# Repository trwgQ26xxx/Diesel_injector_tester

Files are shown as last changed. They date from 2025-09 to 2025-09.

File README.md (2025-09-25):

# Diesel Injector Tester

**A small tester generating short 200 µs pulses needed for testing the opening of electromagnetic diesel injectors with a selectable repetition period.**

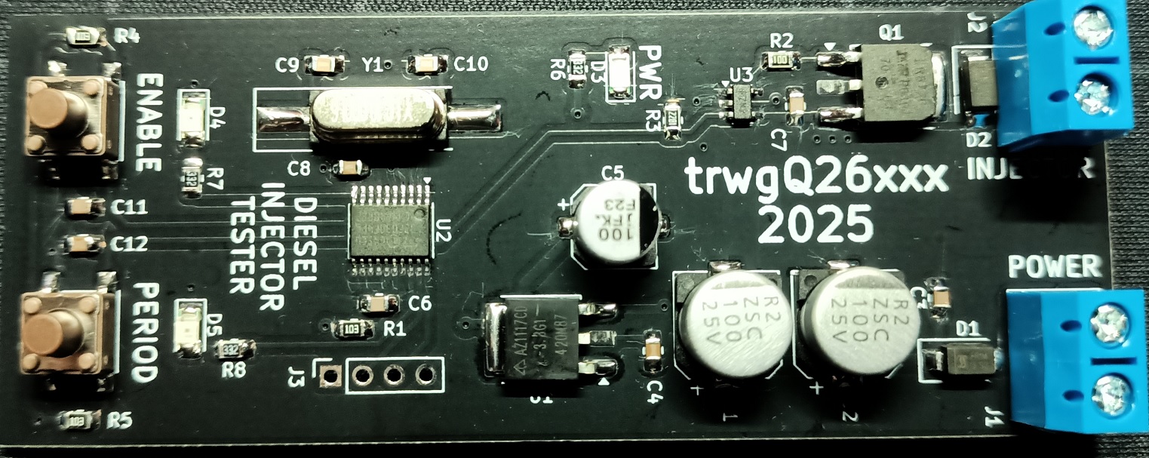
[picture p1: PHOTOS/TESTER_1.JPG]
TESTER_1


Generates high-current, short pulses (200us) with a selectable repetition rate: 0.2Hz, 0.5Hz, 1Hz, 2Hz, 5Hz, or 10Hz.

The tester is operated using two buttons:

* *ENABLE* - Toggles the high-current output on or off.
* *PERIOD* - Cycles through available repetition rates.

Status is indicated by two LEDs:

* *PERIOD* LED blinks at the selected repetition rate.
* *ENABLE* LED is lit when the high-current output is active.

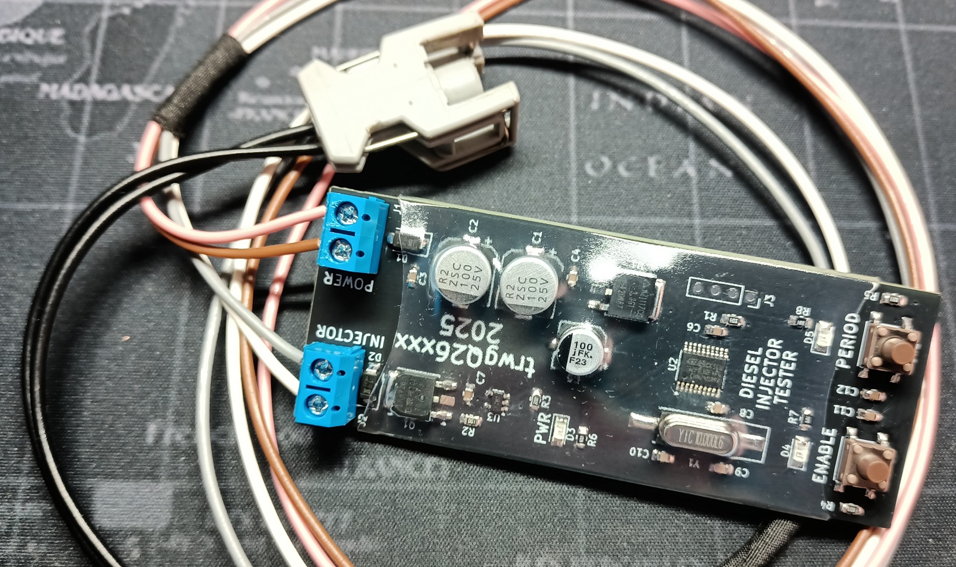
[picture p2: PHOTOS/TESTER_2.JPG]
TESTER_2


# Disclaimer

I do not consent to the use of all or part of the project for commercial purposes!

Nie wyrażam zgody na wykorzystanie całości bądź części projektu w celach zarobkowych!

# License

Shield: [][cc-by-nc-sa]

This work is licensed under a
[Creative Commons Attribution-NonCommercial-ShareAlike 4.0 International License][cc-by-nc-sa].

[][cc-by-nc-sa]

[cc-by-nc-sa]: http://creativecommons.org/licenses/by-nc-sa/4.0/
[cc-by-nc-sa-image]: https://licensebuttons.net/l/by-nc-sa/4.0/88x31.png
[cc-by-nc-sa-shield]: https://img.shields.io/badge/License-CC%20BY--NC--SA%204.0-lightgrey.svg

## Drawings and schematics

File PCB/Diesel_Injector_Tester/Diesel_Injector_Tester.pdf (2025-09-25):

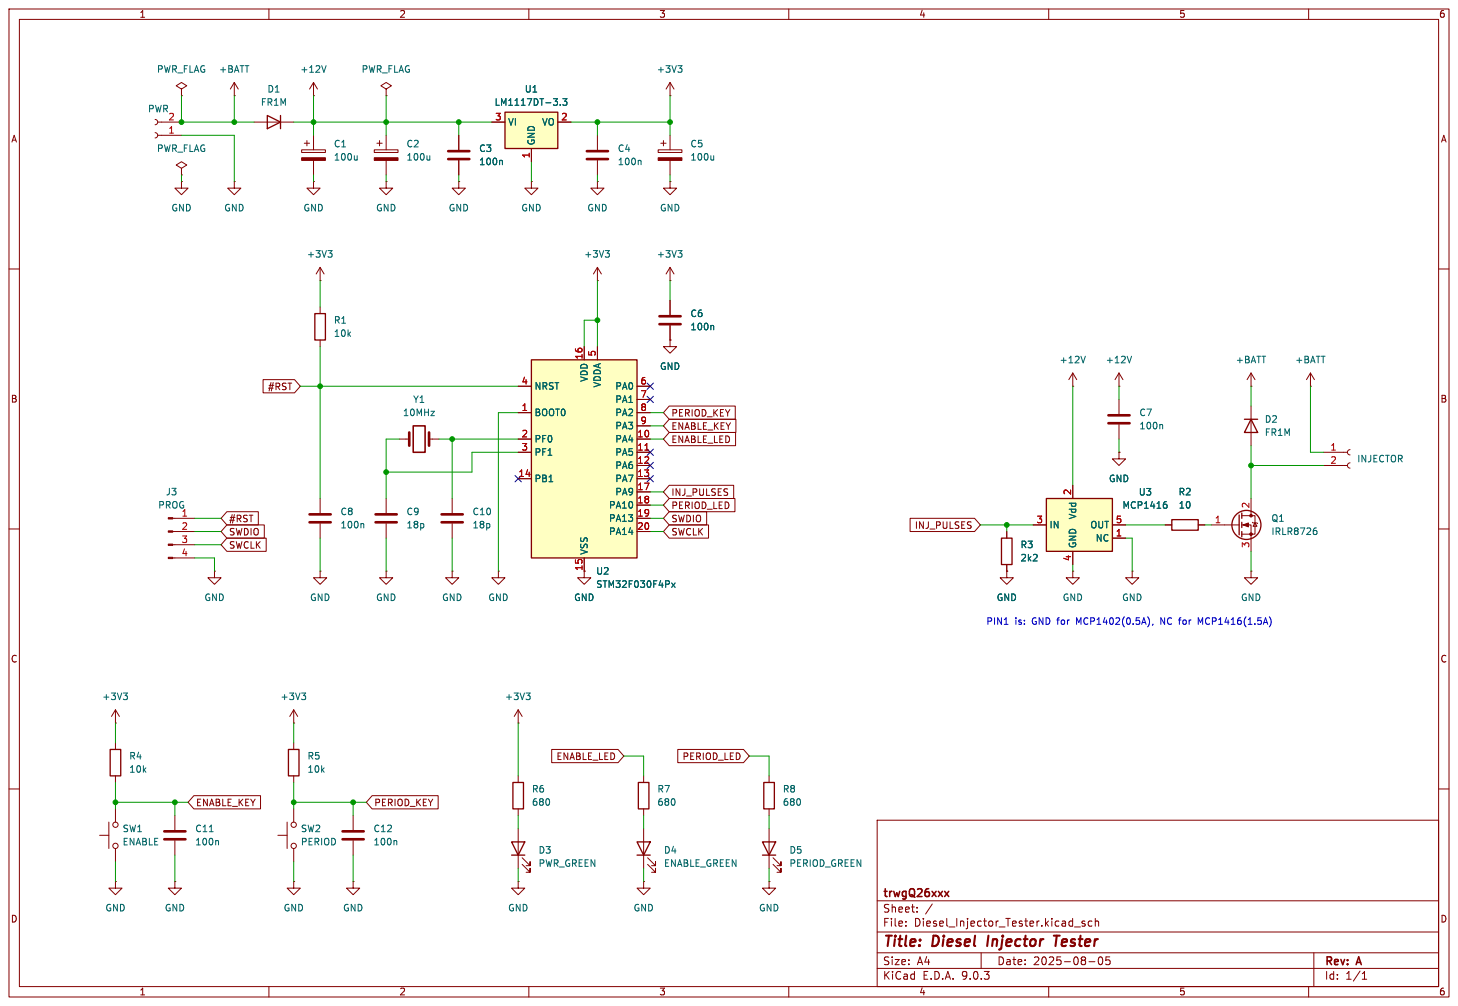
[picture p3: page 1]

Id: 1/1 Title: Diesel Injector Tester File: Diesel_Injector_Tester.kicad_sch Sheet: / trwgQ26xxx

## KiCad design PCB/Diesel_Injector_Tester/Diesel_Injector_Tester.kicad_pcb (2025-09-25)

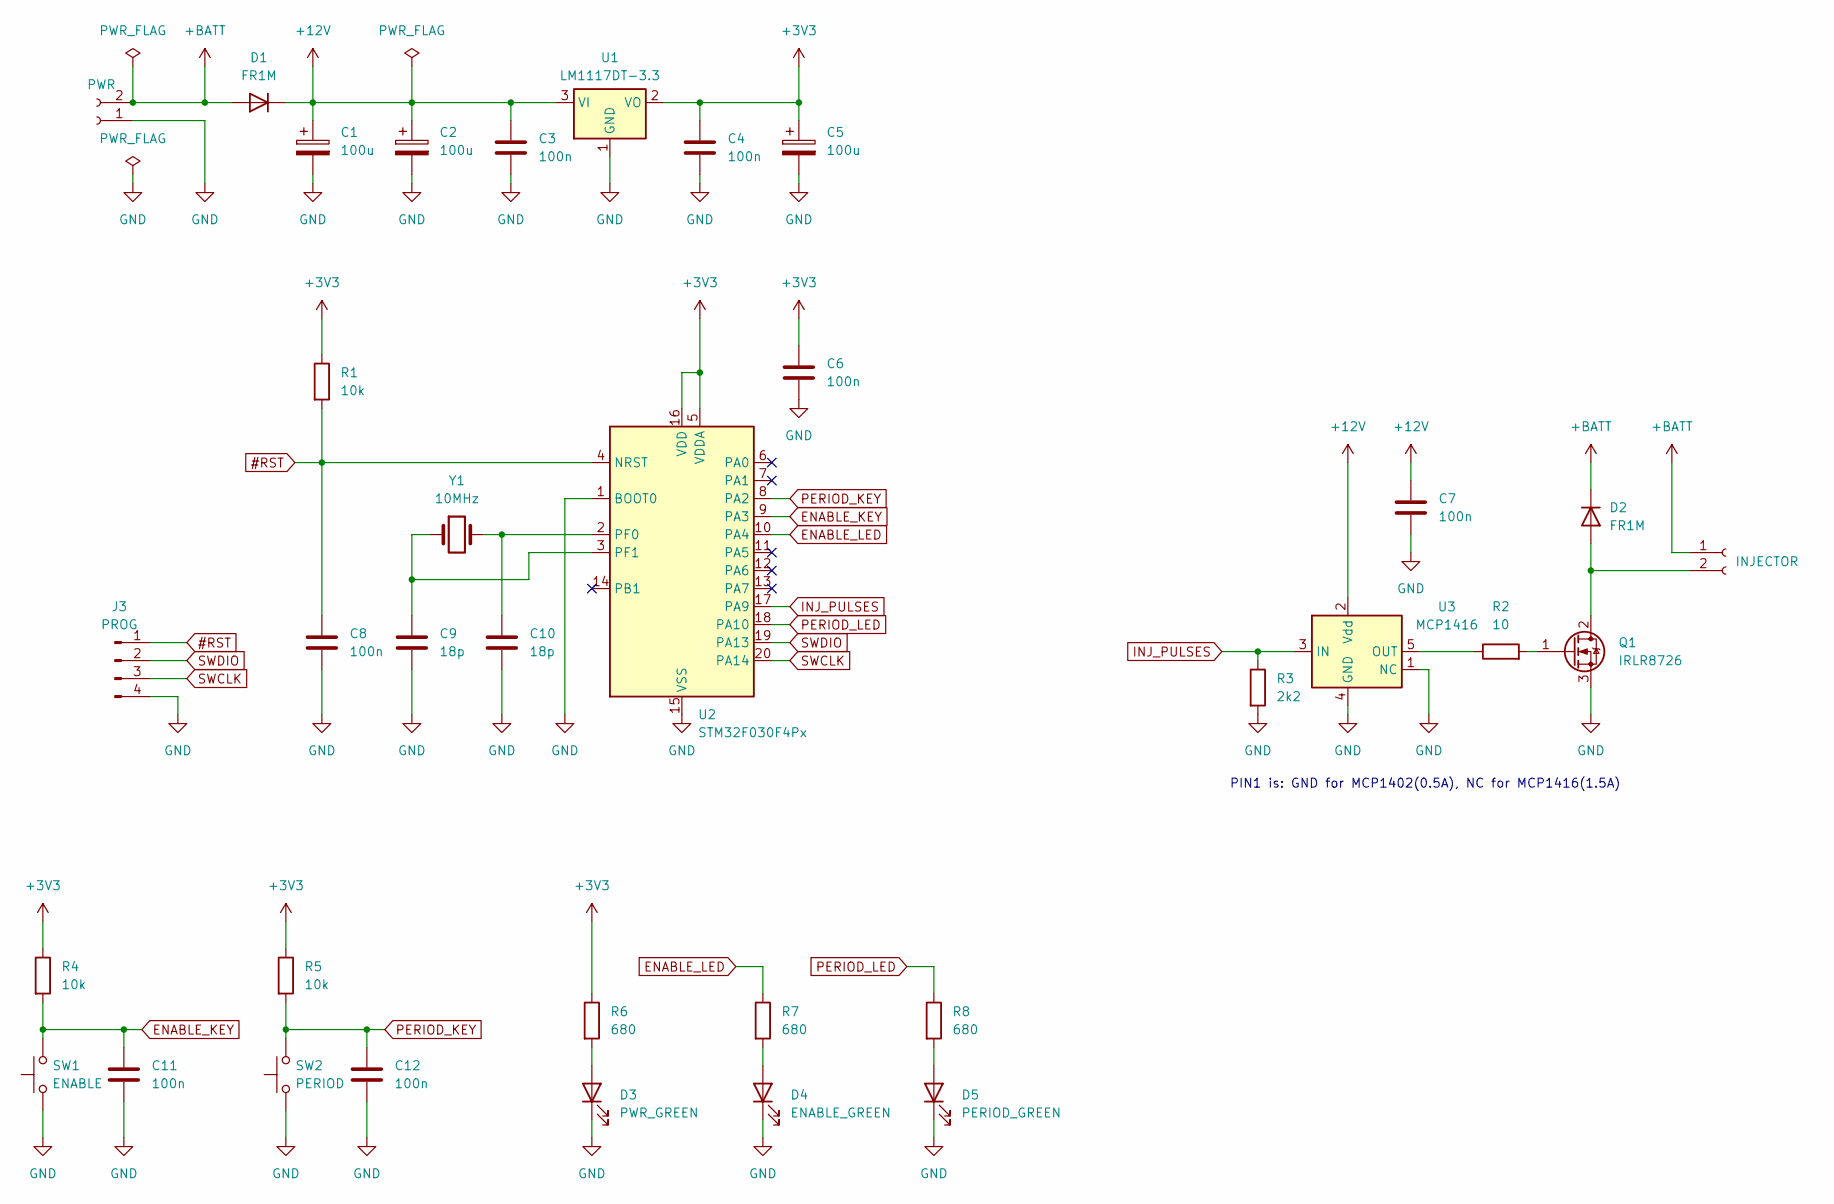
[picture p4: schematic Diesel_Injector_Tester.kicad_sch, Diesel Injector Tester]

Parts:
C1, C2: 100u; CP_Elec_8x6.5
C3, C4, C6, C7, C8, C11, C12: 100n; C_0805_2012Metric_Pad1.18x1.45mm_HandSolder
C5: 100u; CP_Elec_6.3x5.8
C9, C10: 18p; C_0805_2012Metric_Pad1.18x1.45mm_HandSolder
D1, D2: FR1M; D_SMA
D3: PWR_GREEN; LED_1206_3216Metric_Pad1.42x1.75mm_HandSolder
D4: ENABLE_GREEN; LED_1206_3216Metric_Pad1.42x1.75mm_HandSolder
D5: PERIOD_GREEN; LED_1206_3216Metric_Pad1.42x1.75mm_HandSolder
J1: PWR; TerminalBlock_bornier-2_P5.08mm
J2: INJECTOR; TerminalBlock_bornier-2_P5.08mm
J3: PROG; PinSocket_1x04_P2.54mm_Vertical
Q1: IRLR8726; TO-252-3_TabPin2
R1, R4, R5: 10k; R_0805_2012Metric_Pad1.20x1.40mm_HandSolder
R2: 10; R_0805_2012Metric_Pad1.20x1.40mm_HandSolder
R3: 2k2; R_0805_2012Metric_Pad1.20x1.40mm_HandSolder
R6, R7, R8: 680; R_0805_2012Metric_Pad1.20x1.40mm_HandSolder
SW1: ENABLE; SW_SPST_PTS645
SW2: PERIOD; SW_SPST_PTS645
U1: LM1117DT-3.3; TO-252-3_TabPin2
U2: STM32F030F4Px; TSSOP-20_4.4x6.5mm_P0.65mm
U3: MCP1416; SOT-23-5
Y1: 10MHz; Crystal_SMD_HC49-SD_HandSoldering

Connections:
#RST: C8.1, J3.1, R1.2, U2.4 (NRST)
+3V3: C4.1, C5.1, C6.1, R1.1, R4.1, R5.1, R6.1, U1.2 (VO), U2.5 (VDDA), U2.16 (VDD)
+12V: C1.1, C2.1, C3.1, C7.1, D1.1 (K), U1.3 (VI), U3.2 (Vdd)
+BATT: D1.2 (A), D2.1 (K), J1.2, J2.1
ENABLE_KEY: C11.1, R4.2, SW1.2, U2.9 (PA3)
ENABLE_LED: R7.1, U2.10 (PA4)
GND: C1.2, C2.2, C3.2, C4.2, C5.2, C6.2, C7.2, C8.2, C9.2, C10.2, C11.2, C12.2, D3.1 (K), D4.1 (K), D5.1 (K), J1.1, J3.4, Q1.3 (S), R3.2, SW1.1, SW2.1, U1.1 (GND), U2.1 (BOOT0), U2.15 (VSS), U3.1 (NC), U3.4 (GND)
INJ_PULSES: R3.1, U2.17 (PA9), U3.3 (IN)
unnamed: D2.2 (A), J2.2, Q1.2 (D)
unnamed: D3.2 (A), R6.2
unnamed: D4.2 (A), R7.2
unnamed: D5.2 (A), R8.2
unnamed: Q1.1 (G), R2.2
unnamed: C10.1, U2.2 (PF0), Y1.2
unnamed: C9.1, U2.3 (PF1), Y1.1
unnamed: R2.1, U3.5 (OUT)
PERIOD_KEY: C12.1, R5.2, SW2.2, U2.8 (PA2)
PERIOD_LED: R8.1, U2.18 (PA10)
SWCLK: J3.3, U2.20 (PA14)
SWDIO: J3.2, U2.19 (PA13)

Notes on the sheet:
PIN1 is: GND for MCP1402(0.5A), NC for MCP1416(1.5A)

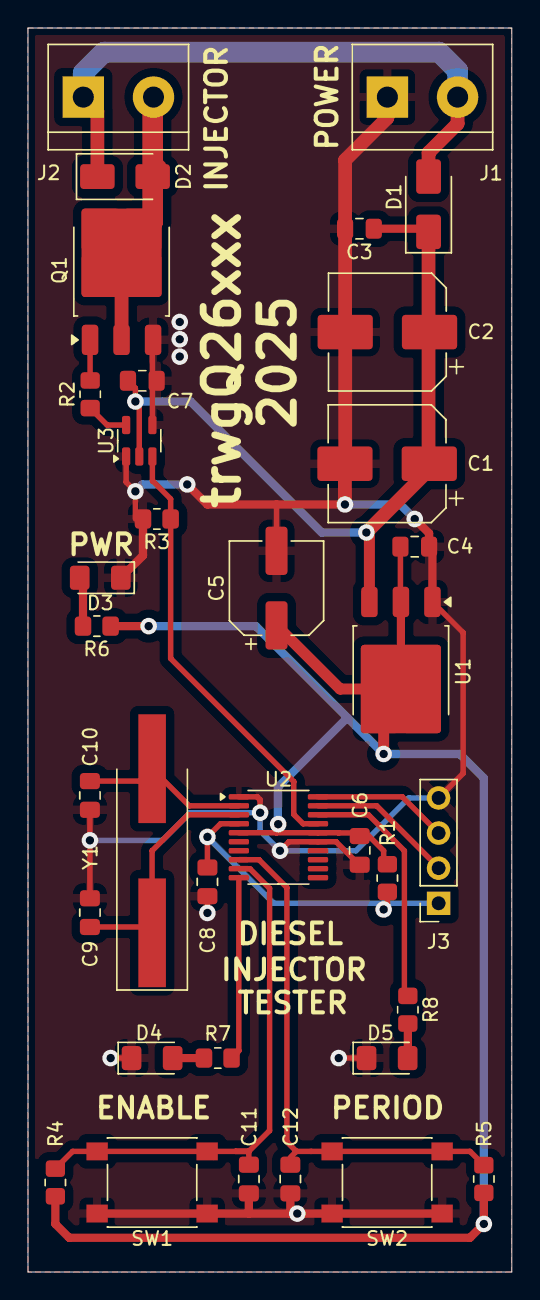
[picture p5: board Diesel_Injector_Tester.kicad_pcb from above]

Board: 2 copper layers, 35.0 x 90.0 mm, 35 parts (0 on the bottom side), 20 nets.

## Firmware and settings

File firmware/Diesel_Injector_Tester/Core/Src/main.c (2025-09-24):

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
/* Includes ------------------------------------------------------------------*/
#include "main.h"
#include "iwdg.h"
#include "tim.h"
#include "gpio.h"

/* USER CODE BEGIN Includes */
#include <stdint.h>
#include <stdbool.h>
/* USER CODE END Includes */


void SystemClock_Config(void);
/* USER CODE BEGIN 0 */

/* ----------------------------------- LED ----------------------------------- */

/* LEDs definitions */
#define ENABLE_LED_ON			LL_GPIO_SetOutputPin(ENABLE_LED_GPIO_Port, ENABLE_LED_Pin)
#define ENABLE_LED_OFF			LL_GPIO_ResetOutputPin(ENABLE_LED_GPIO_Port, ENABLE_LED_Pin)

/* ------------------------------ OUTPUT TIMER ------------------------------- */

/* Injector periods */
#define NUMBER_OF_PERIODS	6
#define DEFAULT_PERIOD_IDX	2	//1Hz

#define MINIMUM_PERIOD		500	//20Hz

void Init_output_timer(uint16_t default_period)
{
	/* Set default period */
	LL_TIM_SetAutoReload(TIM1, (default_period > MINIMUM_PERIOD) ? (default_period - 1) : MINIMUM_PERIOD);

	/* Enable outputs */
	LL_TIM_EnableAllOutputs(TIM1);

	/* Enable counter */
	LL_TIM_EnableCounter(TIM1);

	/* Enable pulse LED, disable INJ pulses */
	LL_TIM_CC_EnableChannel(TIM1, LL_TIM_CHANNEL_CH3);
	LL_TIM_CC_DisableChannel(TIM1, LL_TIM_CHANNEL_CH2);
}

void Change_output_timer_period(uint16_t period, uint8_t pulses_enabled)
{
	/* Disable outputs and timer counter */
	LL_TIM_CC_DisableChannel(TIM1, LL_TIM_CHANNEL_CH2);
	LL_TIM_CC_DisableChannel(TIM1, LL_TIM_CHANNEL_CH3);
	LL_TIM_DisableCounter(TIM1);

	/* Reset counter */
	LL_TIM_SetCounter(TIM1, 0);

	/* Change period */
	LL_TIM_SetAutoReload(TIM1, (period > MINIMUM_PERIOD) ? (period - 1) : MINIMUM_PERIOD);

	/* Enable LED */
	LL_TIM_CC_EnableChannel(TIM1, LL_TIM_CHANNEL_CH3);

	/* Enable INJ pulses back only if flag is set */
	if(pulses_enabled == true)
	{
		LL_TIM_CC_EnableChannel(TIM1, LL_TIM_CHANNEL_CH2);
	}

	/* Enable counter back again */
	LL_TIM_EnableCounter(TIM1);
}

/* -------------------------------- KEYBOARD --------------------------------- */

/* Keyboard definitions */
#define KEYBOARD_DEBOUNCE_TIME	200	//ms

#define PERIOD_KEY_IS_PRESSED	(!(LL_GPIO_IsInputPinSet(PERIOD_KEY_GPIO_Port, PERIOD_KEY_Pin)))
#define ENABLE_KEY_IS_PRESSED	(!(LL_GPIO_IsInputPinSet(ENABLE_KEY_GPIO_Port, ENABLE_KEY_Pin)))
#define ALL_KEYS_ARE_RELEASED	(LL_GPIO_IsInputPinSet(PERIOD_KEY_GPIO_Port, PERIOD_KEY_Pin) && LL_GPIO_IsInputPinSet(ENABLE_KEY_GPIO_Port, ENABLE_KEY_Pin))

#define CLEAR_KBD_TIMER			LL_TIM_SetCounter(TIM14, 0)

enum KEYBOARD_KEYS
{
	NO_KEY		= 0,
	PERIOD_KEY	= 1,
	ENABLE_KEY	= 2
};

volatile uint8_t keyboard_locked = true;

void Init_keyboard(void)
{
	/* Keyboard is locked by default, to prevent accidental changes */
	keyboard_locked = true;

	/* Init keyboard timer */
	LL_TIM_EnableCounter(TIM14);

	/* Clear keyboard timer */
	CLEAR_KBD_TIMER;
}

uint8_t Get_keyboard_key(void)
{
	uint8_t key = NO_KEY;

	/* Check if keyboard is unlocked */
	if(keyboard_locked == false)
	{
		if(PERIOD_KEY_IS_PRESSED)
		{
			/* If PERIOD key is pressed, set key to PERIOD_KEY */
			key = PERIOD_KEY;

			/* Debounce keys */
			keyboard_locked = true;
			CLEAR_KBD_TIMER;
		}
		else if(ENABLE_KEY_IS_PRESSED)
		{
			/* If ENABLE key is pressed, set key to ENABLE_KEY */
			key = ENABLE_KEY;

			/* Debounce keys */
			keyboard_locked = true;
			CLEAR_KBD_TIMER;
		}
	}
	else
	{
		/* If keyboard is locked, check if timer has expired */
		if(LL_TIM_GetCounter(TIM14) > KEYBOARD_DEBOUNCE_TIME)
		{
			/* Unlock keyboard if all keys are released */
			if(ALL_KEYS_ARE_RELEASED)
			{
				/* Unlock keyboard */
				keyboard_locked = false;
			}
			else
			{
				/* Reset timer, wait another period */
				CLEAR_KBD_TIMER;
			}
		}

		/* If keyboard is locked, return NO_KEY */
		key = NO_KEY;
	}

	return key;
}

/* USER CODE END 0 */

/**
  * @brief  The application entry point.
  * @retval int
  */
int main(void)
{

  /* MCU Configuration--------------------------------------------------------*/

  /* Reset of all peripherals, Initializes the Flash interface and the Systick. */
  LL_APB1_GRP2_EnableClock(LL_APB1_GRP2_PERIPH_SYSCFG);
  LL_APB1_GRP1_EnableClock(LL_APB1_GRP1_PERIPH_PWR);

  /* SysTick_IRQn interrupt configuration */
  NVIC_SetPriority(SysTick_IRQn, 3);

  /* Configure the system clock */
  SystemClock_Config();

  /* Initialize all configured peripherals */
  MX_GPIO_Init();
  MX_TIM1_Init();
  MX_TIM14_Init();
  MX_IWDG_Init();
  /* USER CODE BEGIN 2 */

	/* Handle WDT */
	LL_IWDG_ReloadCounter(IWDG);

	const uint16_t auto_reload_periods[NUMBER_OF_PERIODS] = {50000, 20000, 10000, 5000, 2000, 1000};	//0.2Hz, 0.5Hz, 1Hz, 2Hz, 5Hz, 10Hz

	uint8_t injector_pulses_enabled	= false;
	uint8_t current_period			= DEFAULT_PERIOD_IDX;

	ENABLE_LED_OFF;

	/* Init output timer */
	Init_output_timer(auto_reload_periods[DEFAULT_PERIOD_IDX]);	//1Hz

	/* Init keyboard */
	Init_keyboard();

  /* USER CODE END 2 */

  /* Infinite loop */
  /* USER CODE BEGIN WHILE */
	while (1)
	{
		switch(Get_keyboard_key())
		{
			case PERIOD_KEY:

				/* Switch to next period */
				current_period++;
				if(current_period >= NUMBER_OF_PERIODS)
				{
					current_period = 0;
				}

				/* Update settings */
				Change_output_timer_period(auto_reload_periods[current_period], injector_pulses_enabled);
				break;

			case ENABLE_KEY:

				/* Toggle enable flag */
				if(injector_pulses_enabled == true)
				{
					ENABLE_LED_OFF;

					injector_pulses_enabled = false;
				}
				else
				{
					ENABLE_LED_ON;

					injector_pulses_enabled = true;
				}

				/* Update settings */
				Change_output_timer_period(auto_reload_periods[current_period], injector_pulses_enabled);
				break;

			default:

				/* No key pressed, do nothing */
				break;
		}

		/* Handle WDT */
		LL_IWDG_ReloadCounter(IWDG);
    /* USER CODE END WHILE */

    /* USER CODE BEGIN 3 */
	}
  /* USER CODE END 3 */
}

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


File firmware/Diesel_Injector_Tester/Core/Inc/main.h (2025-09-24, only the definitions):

#define PERIOD_KEY_Pin LL_GPIO_PIN_2
#define PERIOD_KEY_GPIO_Port GPIOA
#define ENABLE_KEY_Pin LL_GPIO_PIN_3
#define ENABLE_KEY_GPIO_Port GPIOA
#define ENABLE_LED_Pin LL_GPIO_PIN_4
#define ENABLE_LED_GPIO_Port GPIOA
#define INJ_PULSES_Pin LL_GPIO_PIN_9
#define INJ_PULSES_GPIO_Port GPIOA
#define PERIOD_LED_Pin LL_GPIO_PIN_10
#define PERIOD_LED_GPIO_Port GPIOA
#define NVIC_PRIORITYGROUP_0         ((uint32_t)0x00000007) /*!< 0 bit  for pre-emption priority,
#define NVIC_PRIORITYGROUP_1         ((uint32_t)0x00000006) /*!< 1 bit  for pre-emption priority,
#define NVIC_PRIORITYGROUP_2         ((uint32_t)0x00000005) /*!< 2 bits for pre-emption priority,
#define NVIC_PRIORITYGROUP_3         ((uint32_t)0x00000004) /*!< 3 bits for pre-emption priority,
#define NVIC_PRIORITYGROUP_4         ((uint32_t)0x00000003) /*!< 4 bits for pre-emption priority,

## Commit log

2025-08-05 Project updated to STM32CubeIDE 1.19.0 and added to repository
2025-08-05 Schematic added, footprints assigned
    [Diesel_Injector_Tester.kicad_pcb, Diesel_Injector_Tester.kicad_sch]
2025-08-05 Schematic in PDF added
2025-08-23 PCB prepared, schematic updated
    [Diesel_Injector_Tester.kicad_pcb, Diesel_Injector_Tester.kicad_sch]
2025-09-24 Changed signal names to reflect ones from schematic, changed crystal from 8MHz to 10MHz
2025-09-24 Changed ENABLE_LED logic to reflect schematic
2025-09-25 Schematic updated for final component values
    [Diesel_Injector_Tester.kicad_sch]
2025-09-25 Update related to GERBER files generation
    [Diesel_Injector_Tester.kicad_pcb]

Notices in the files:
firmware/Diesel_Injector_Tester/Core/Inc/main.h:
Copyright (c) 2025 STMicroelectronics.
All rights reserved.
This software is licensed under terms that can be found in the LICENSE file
